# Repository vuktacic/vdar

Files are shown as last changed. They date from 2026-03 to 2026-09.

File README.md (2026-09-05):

# vdar

vdar is a low-cost 3D lidar scanner using the TF-Luna. It can generate point clouds of it's environment, which can be visualized with [vvis](./vvis). vdar is completely open source, and was designed for Hack Club's [Stasis program](https://stasis.hackclub.com). vdar was also exhibited at [Open Sauce 2026](https://www.opensauce.com/)

I created vdar because of a general interest in LiDAR. I've been playing with point clouds for a few years, and wanted to create a device that could generate my own clouds. I also wanted to learn how to create a mechanically more complex design, combined with designing and manufacturing an actual PCB.

[vdar Youtube Video](https://www.youtube.com/shorts/brxcMjVyBjw)

## Repo Structure

- [`./hardware`](./hardware) - Design files for vdar
  - [`./hardware/cad`](./hardware/cad) - Fusion 360 & Step design files for vdar
  - [`./hardware/pcb`](./hardware/pcb) - KiCad design files for vdar
    - [`./hardware/pcb/production`](./hardware/pcb/production) - PCB Production files (gerbers.zip)
- [`./JOURNAL.md`](./JOURNAL.md) - Development Journal for vdar
- [`./project`](./project) - Project management files for vdar
    - [`./project/assets`](./project/assets) - Media for project files
    - [`./project/docs`](./project/docs) - Assembly instructions for vdar
    - [`./project/finances`](./project/finances) - BOM & POs for vdar
- [`./vcore`](./vcore) - ESP32 firmware for vdar
- [`./vvis`](./vvis) - NodeJS visualizer for vdar

## Quick Start
Requirements:
 - PlatformIO Core
 - NodeJS
 - Python3

```bash
git clone https://github.com/vuktacic/vdar.git
cd vdar
just setup
mv ./vcore/include/secrets.h.example ./vcore/include/secrets.h
```
```bash
just build
just flash
just run
```

## Pictures
### Real life
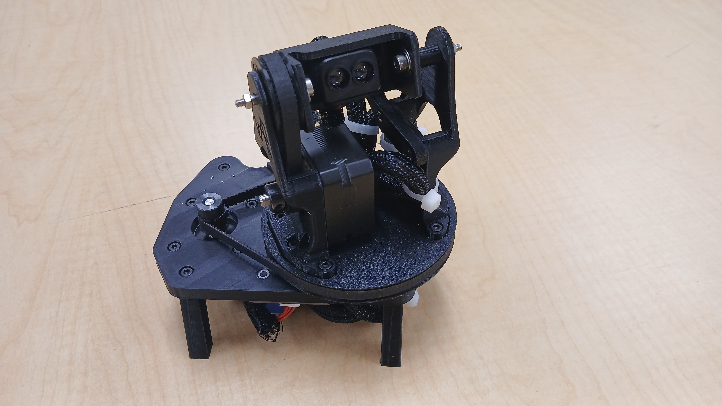
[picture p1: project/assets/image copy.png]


### Scans
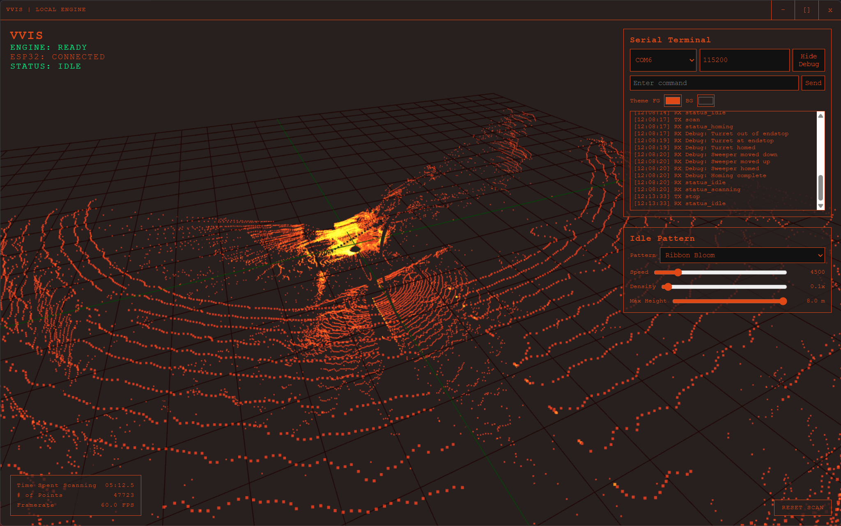
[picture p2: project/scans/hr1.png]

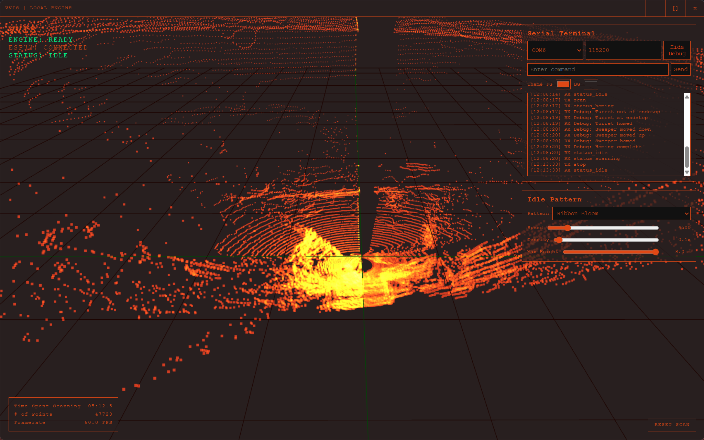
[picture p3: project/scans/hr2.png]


### 3D CAD
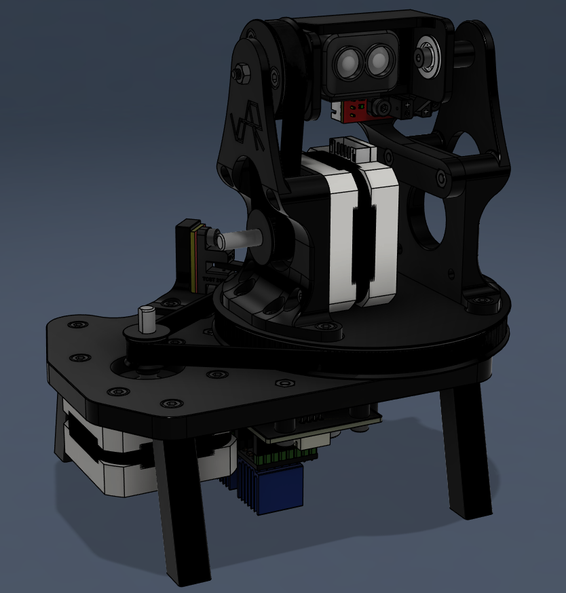
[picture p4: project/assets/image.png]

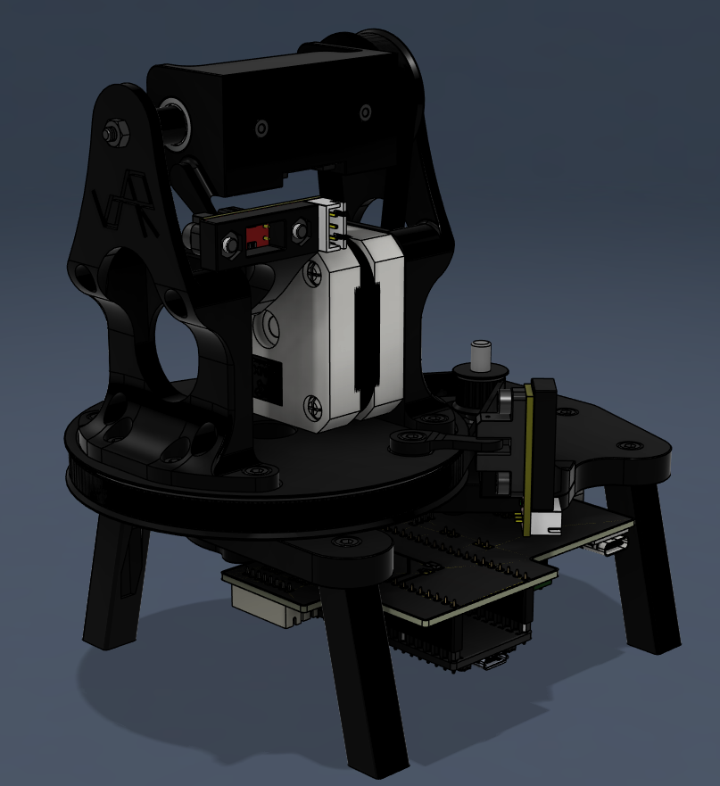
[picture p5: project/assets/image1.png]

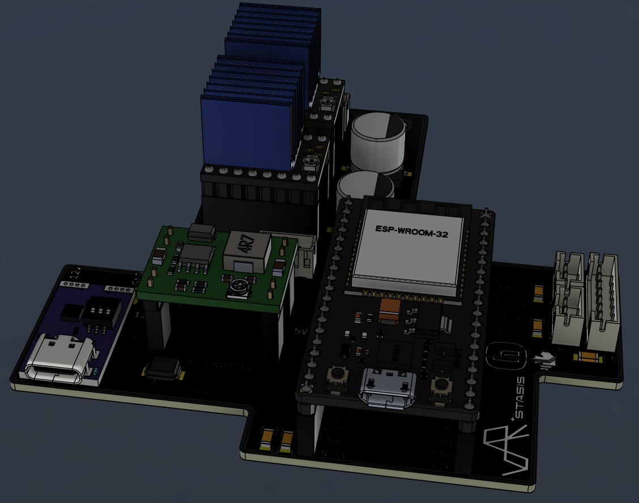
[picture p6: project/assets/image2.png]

### PCB
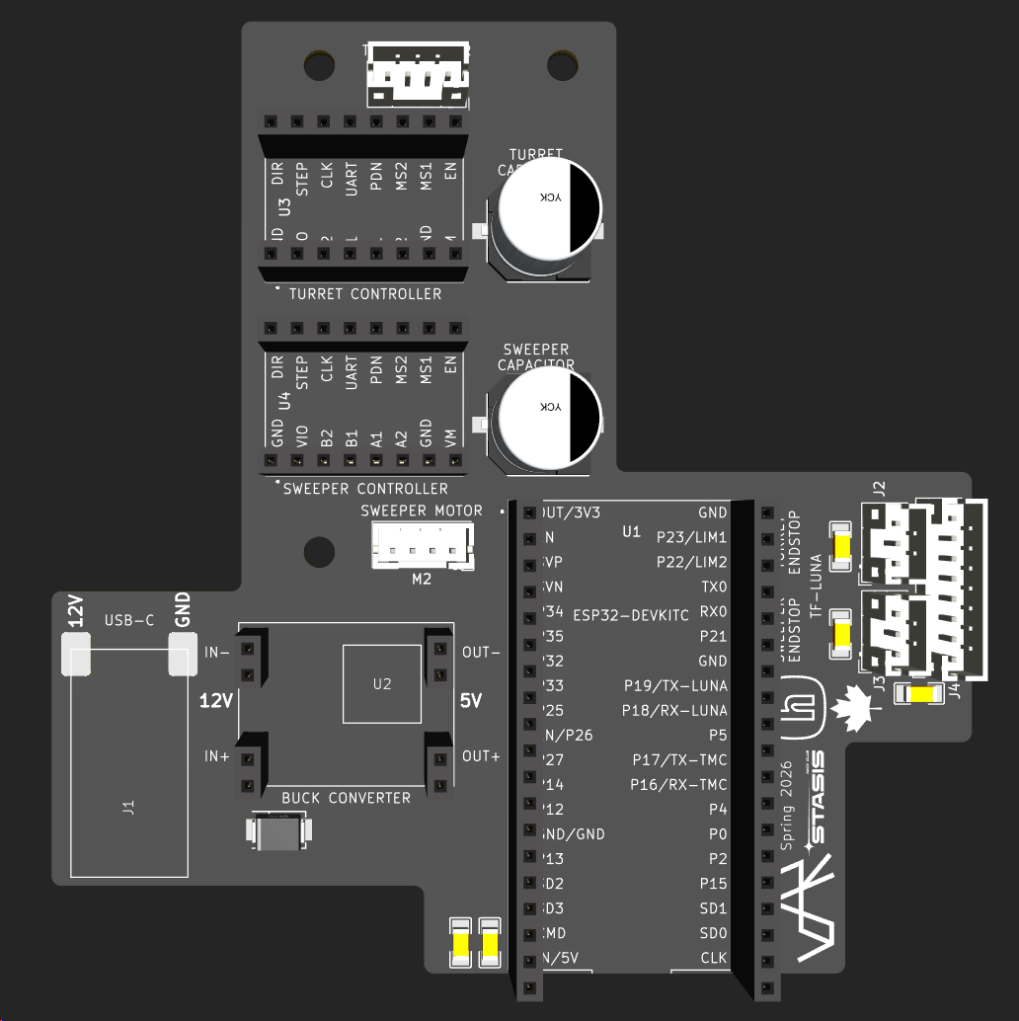
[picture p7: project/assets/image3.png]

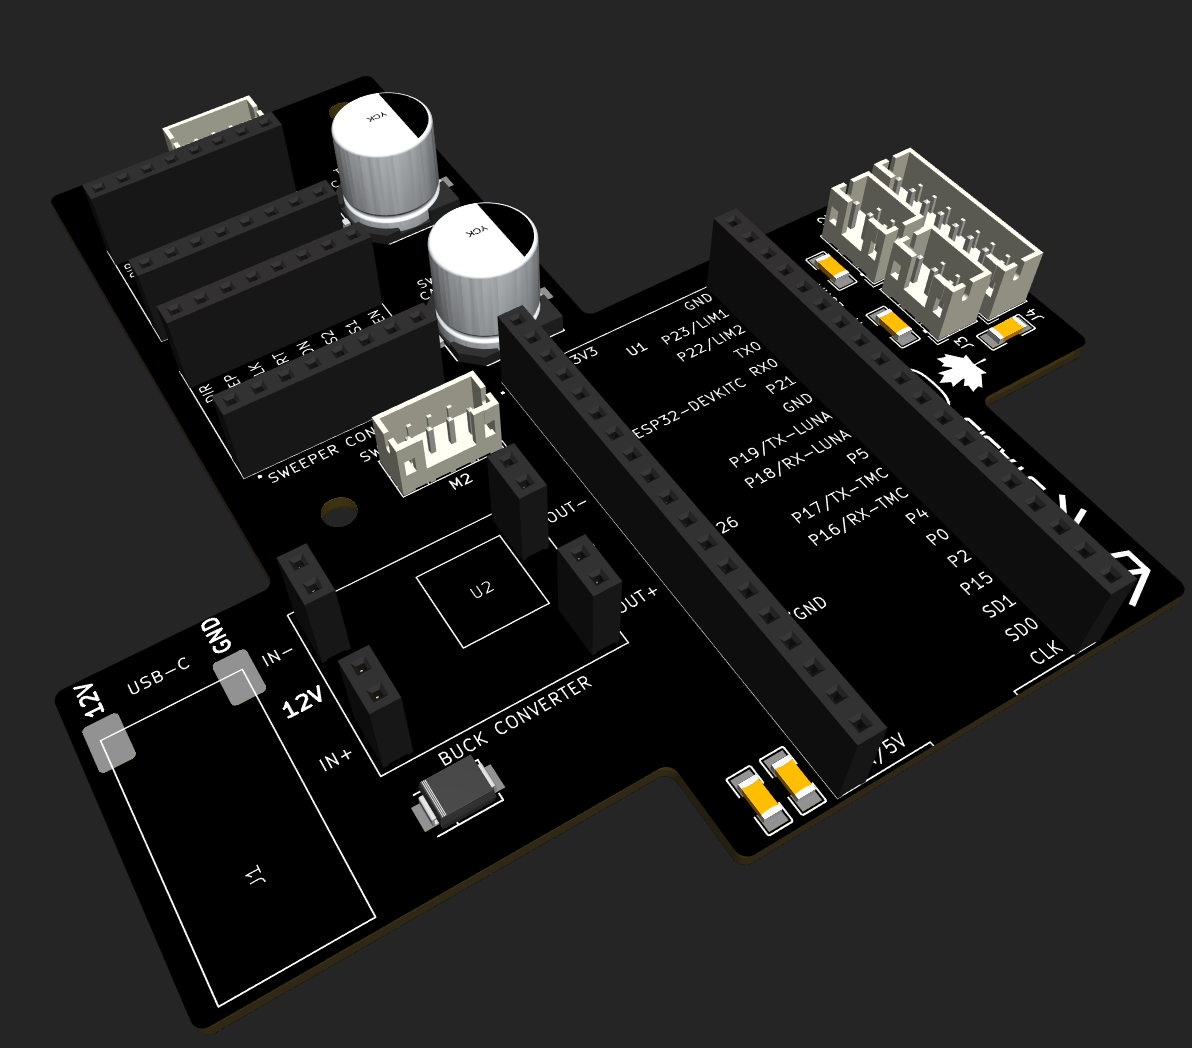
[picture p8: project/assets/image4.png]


### Offboard Wiring
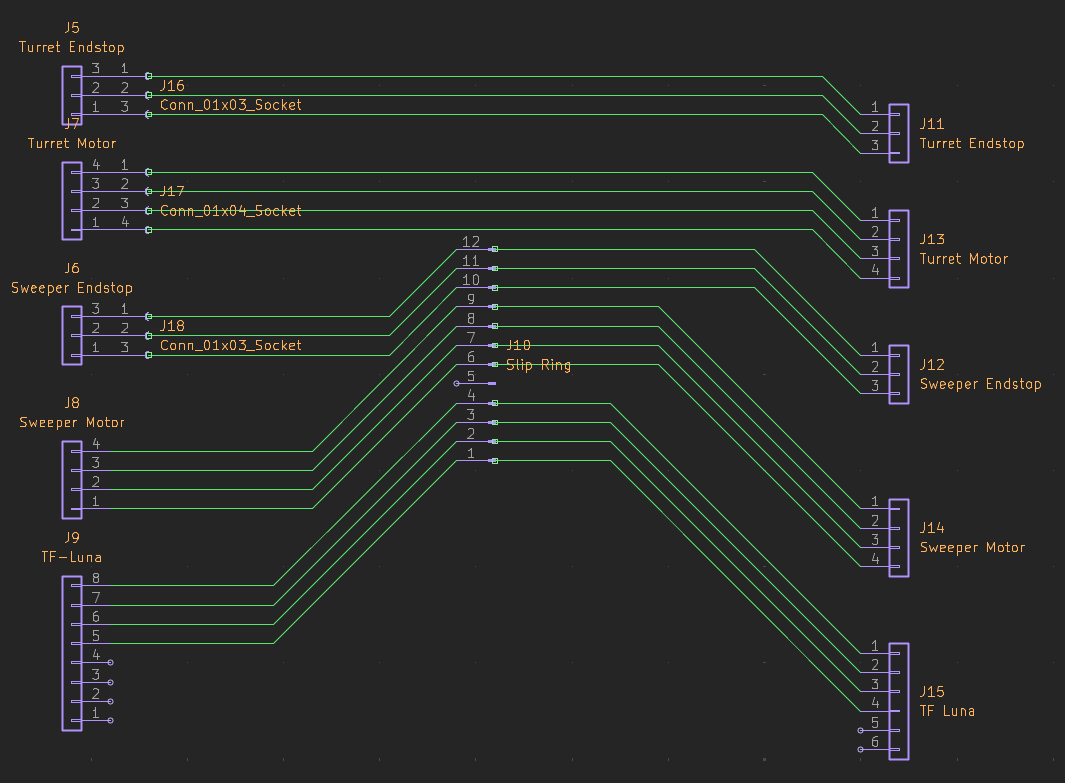
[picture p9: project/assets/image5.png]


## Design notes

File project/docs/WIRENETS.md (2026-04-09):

# Wire Nets for vdar
Map of physical labels to wire nets

## Turret Motor
- A - M1A_1
- B - M1B_1
- C - M2A_1
- D - M2B_1

## Sweeper Motor
- E - M1A_2
- F - M1B_2
- G - M2A_2
- H - M2B_2

## Turret Endstop
- I - VIN
- J - SIG
- K - GND

## Sweeper Endstop
- L - VIN
- M - SIG
- N - GND

## TF-LUNA
- O - VIN
- P - ESP-LUNA
- Q - LUNA-ESP
- R - GND

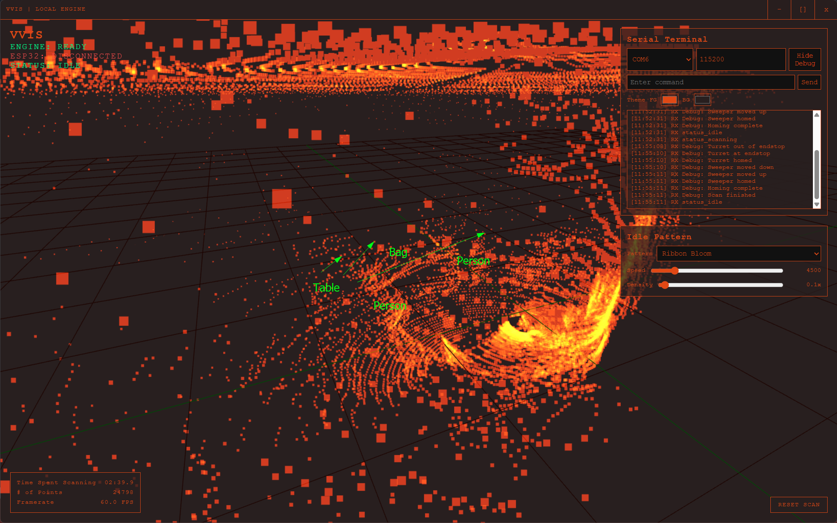
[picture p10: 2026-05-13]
project/scans/scanview2.png

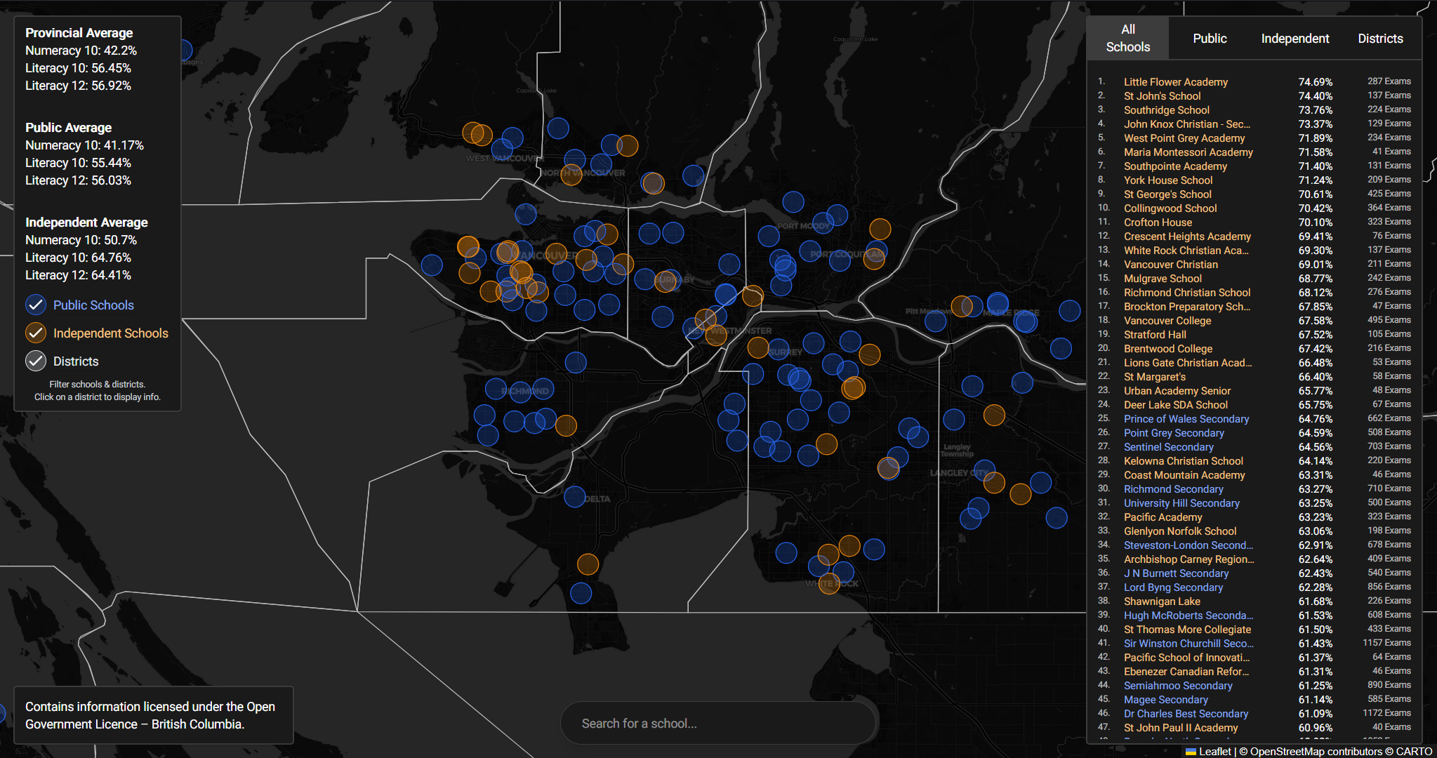
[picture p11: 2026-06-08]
project/scans/screenshot.png

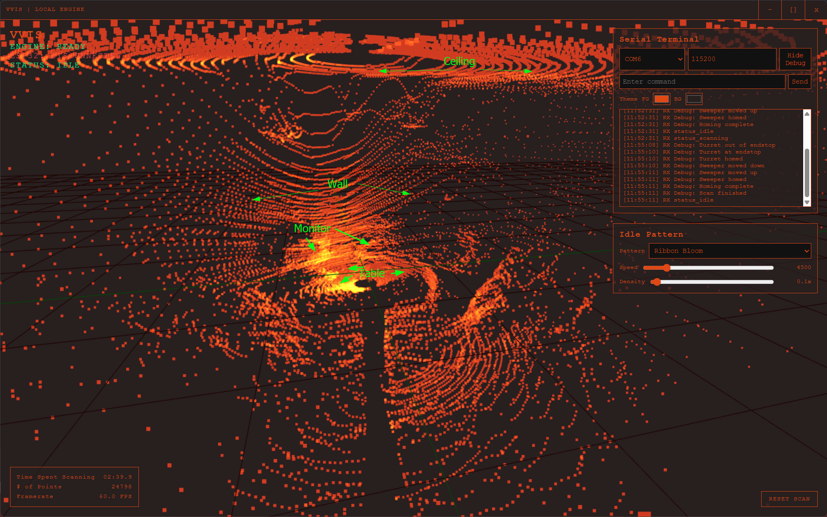
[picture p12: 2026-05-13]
project/scans/scanview1.png

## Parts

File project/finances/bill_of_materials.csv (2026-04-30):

Ordered | On-hand | Item | Vendor | Qty
:--- | :--- | :--- | :--- | :---
**Mechanical**
[x] | [x] | [NEMA 17 Motor 17HS4023](https://www.aliexpress.com/item/1005003874936862.html) | AliExpress | 2
[x] | [x] | [6804-2RS (20x32x7) Bearing](https://www.aliexpress.com/item/1005006415114490.html) | AliExpress | 1
[x] | [x] | [F604-ZZ (4x22x4) Bearing](https://www.aliexpress.com/item/1005006868220737.html) | AliExpress | 2
[x] | [x] | [165T 6mm Wide 2mm Pitch GT2 Timing Belt](https://www.aliexpress.com/item/1005005092316899.html) | AliExpress | 1
[x] | [x] | [85T 6mm Wide 2mm Pitch GT2 Timing Belt](https://www.aliexpress.com/item/1005007811742786.html) | AliExpress | 1
**3D Printed**
[x] | [x] | Main Plate | Home | 1
[x] | [x] | Bottom Plate | Home | 1
[x] | [x] | Tower | Home | 2
[x] | [x] | Yoke | Home | 1
[x] | [x] | Turret Endstop Connector | Home | 1
[x] | [x] | Sweeper Endstop Connector | Home | 1
[x] | [x] | Turret Jut | Home | 1
[x] | [x] | Leg | Home | 4
[ ] | [ ] | Yoke Right Spacer (11.8mm Long) | Home | 1
[ ] | [ ] | Yoke Left Spacer (0.6mm Long) | Home | 1
[ ] | [ ] | PCB Spacer (7.4mm Long) | Home | 3
[x] | [ ] | 144T Turret Pulley | Home | 1
[x] | [ ] | 20T Turret Pinion | Home | 1
[x] | [ ] | 45T Sweeper Pulley | Home | 1
[x] | [ ] | 25T Sweeper Pinion | Home | 1
**Fasteners**
[x] | [x] | M2x5 Hex Socket Cap Screw | Fastenal | 2
[x] | [x] | M2 Hex Nut | Fastenal | 2
[x] | [x] | M3x6 Hex Socket Cap Screw | Fastenal | 5
[x] | [x] | M3x8 Hex Socket Cap Screw | Fastenal | 10
[x] | [x] | M3x10 Hex Socket Cap Screw | Fastenal | 23
[x] | [x] | M3x16 Hex Socket Cap Screw | Fastenal | 3
[x] | [x] | M3 Hex Nut | Fastenal | 35
[x] | [x] | M3D4x20 Hex Socket Cap Shoulder Bolt | Aliexpress | 2
**Electronics**
[x] | [x] | [Benewake TF-Luna 250Hz LIDAR Sensor](https://www.aliexpress.com/item/1005009516099639.html) | AliExpress | 1
[x] | [x] | [Optical Endstop](https://www.aliexpress.com/item/1005005231591120.html) | AliExpress | 2
[x] | [x] | [TMC2209 Stepper Driver](https://www.aliexpress.com/item/1005006323811276.html) | AliExpress | 2
[x] | [x] | [MP1584EN Devboard Buck Converter](https://www.aliexpress.com/item/1005007136976280.html) | AliExpress | 1
[x] | [x] | [12 Wire 2A Slip Ring](https://www.aliexpress.com/item/1005007805413865.html) | AliExpress | 1
[x] | [x] | [USB C Decoy Board](https://www.aliexpress.com/item/1005005622939899.html) | AliExpress | 1
[x] | [x] | ESP32 DevKit-C | Home | 1
[x] | [x] | PCB | JLCPCB | 1
[x] | [x] | [35V 470μF Capacitor](https://www.aliexpress.com/item/1005006853348605.html) | Aliexpress | 2
[x] | [x] | [25V 10μF 1206 Capacitor](https://leeselectronic.com/en/product/81793-smd-capacitor-10uf-25v-1206.html) | Lee's Electronics | 1
[x] | [x] | [50V 100nF 1206 Capacitor](https://www.aliexpress.com/item/1005010653487250.html) | Aliexpress | 4
[x] | [x] | [1kΩ 1206 Resistor](https://leeselectronic.com/en/product/914154-resistors-smd-1k-5-1206-20pcs.html) | Lee's Electronics | 1
[x] | [x] | [15Vrwm 16.7Vbr 24.4VC SMBJ15A TVS Diode](https://www.aliexpress.com/item/1005007161640002.html) | Aliexpress | 1
[x] | [x] | 1x3 Pin JST-PH Male Header | School | 4
[x] | [x] | 1x4 Pin JST-PH Male Header | School | 4
[x] | [x] | 1x8 Pin JST-PH Male Header | School | 3
[x] | [x] | 1x3 Pin JST-PH Female Header | School | 4
[x] | [x] | 1x4 Pin JST-PH Female Header | School | 4
[x] | [x] | 1x8 Pin JST-PH Female Header | School | 3
[x] | [x] | 1x2 Pin 2.54mm Header | School | 4
[x] | [x] | 1x8 Pin 2.54mm Header | School | 4
[x] | [x] | 1x19 Pin 2.54mm Header | School | 2
[x] | [x] | 1x3 Pin JST-PH Female to 1x3 Pin JST-XH Female Cable | School | 2
[x] | [x] | 1x3 Pin JST-PH Female to 1x3 Pin JST-PH Female Cable | School | 1
[x] | [x] | 1x4 Pin JST-PH Female to 1x4 Pin JST-XH Female Cable | School | 2
[x] | [x] | 1x4 Pin JST-PH Female to 1x4 Pin JST-PH Female Cable | School | 1
[x] | [x] | 1x8 Pin JST-PH Female to 1x6 Pin JST-XH Female Cable | School | 1
[x] | [x] | 1x8 Pin JST-PH Female to 1x8 Pin JST-PH Female Cable | School | 1
[x] | [x] | 2m of 24-32 AWG Wire | School | 1
--- | --- | --- | --- | ---

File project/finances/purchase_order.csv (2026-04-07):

Ordered | On-hand | Item | Vendor | Qty | Total Cost (CAD)
:--- | :--- | :--- | :--- | :---
**Mechanical**
[x] | [ ] | [NEMA 17 Motor 17HS4023](https://www.aliexpress.com/item/1005003874936862.html) | AliExpress | 3 | $30.66
[x] | [ ] | [6804-2RS (20x32x7) Bearing](https://www.aliexpress.com/item/1005006415114490.html) | AliExpress | 2 | $6.82
[x] | [ ] | [F604-ZZ (4x22x4) Bearing](https://www.aliexpress.com/item/1005006868220737.html) | AliExpress | 5 | $7.49
[x] | [ ] | [165T 6mm Wide 2mm Pitch GT2 Timing Belt](https://www.aliexpress.com/item/1005005092316899.html) | AliExpress | 1 | $4.61
[x] | [ ] | [85T 6mm Wide 2mm Pitch GT2 Timing Belt](https://www.aliexpress.com/item/1005007811742786.html) | AliExpress | 1 | $2.84
**Fasteners**
[x] | [x] | [M3D4x20 Hex Socket Cap Shoulder Bolt](https://www.aliexpress.com/item/1005008314676042.html) | Aliexpress | 10 | $4.59
**Electronics**
[x] | [x] | [Benewake TF-Luna 250Hz LIDAR Sensor](https://www.aliexpress.com/item/1005009516099639.html) | AliExpress | 1 | $31.18
[x] | [x] | [Optical Endstop](https://www.aliexpress.com/item/1005005231591120.html) | AliExpress | 6 | $6.89
[x] | [ ] | [TMC2209 Stepper Driver](https://www.aliexpress.com/item/1005006323811276.html) | AliExpress | 3 | $12.78
[x] | [ ] | [MP1584EN Devboard Buck Converter](https://www.aliexpress.com/item/1005007136976280.html) | AliExpress | 1 | $1.72
[x] | [ ] | [12 Wire 2A Slip Ring](https://www.aliexpress.com/item/1005007805413865.html) | AliExpress | 1 | $16.32
[x] | [ ] | [USB C Decoy Board](https://www.aliexpress.com/item/1005005622939899.html) | AliExpress | 1 | $1.98
[x] | [ ] | PCB | JLCPCB | 5 | $2.00
[x] | [ ] | PCB Shipping | JLCPCB | 1 | $1.50
[x] | [ ] | [35V 470μF Capacitor](https://www.aliexpress.com/item/1005006853348605.html) | Aliexpress | 10 | $5.23
[x] | [x] | [25V 10μF 1206 Capacitor](https://leeselectronic.com/en/product/81793-smd-capacitor-10uf-25v-1206.html) | Lee's Electronics | 5 | $1.25
[x] | [ ] | [50V 100nF 1206 Capacitor](https://www.aliexpress.com/item/1005010653487250.html) | Aliexpress | 100 | $4.31
[x] | [x] | [1kΩ 1206 Resistor](https://leeselectronic.com/en/product/914154-resistors-smd-1k-5-1206-20pcs.html) | Lee's Electronics | 20 | $2.00
[x] | [ ] | [15Vrwm 16.7Vbr 24.4VC SMBJ15A TVS Diode](https://www.aliexpress.com/item/1005007161640002.html) | Aliexpress | 20 | $4.40
--- | --- | --- | --- | --- | ---
**TOTAL OUTLAY** |  |  |  |  | **$143.06**
**TOTAL OUTLAY (USD)** |  |  |  |  | **$103.98**

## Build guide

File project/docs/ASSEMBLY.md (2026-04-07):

# Hardware Assembly

## 3D Printing

### Materials
- Black PLA

### Print Settings
- Printer: SV06
- Layer height: 0.2mm
- Infill: 15% Gyroid
- Nozzle temp: 205°C
- Bed temp: 60°C
- Print speed: 90 mm/s
- Tree supports

## Assembly Steps

1. Placeholder

## References
See BOM.md for materials list.

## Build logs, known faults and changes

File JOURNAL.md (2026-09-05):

<!--
  This journal is auto generated by Stasis.
-->

# 5/15/2026 10 PM - Finished Project!

_Time spent: 4h_

vdar is finally finished, and it can actually do scans!

There were a couple integration problems, but nothing that wasn't easily fixed. Mainly regarding exact rotation speeds & unit conversions between rps & μsteps per second. All was resolved though, and there were no catastrophic problems!





When I did my first scan, it was horrible. This was fixed by actually. I then encountered insane drift on my azimuth.



It was shifting by like 15° every rotation! At first I checked my numerical integration. That was way off. Even after fixing the integration it was cooked. I checked, and for some reason the motor was slightly inaccurate. The fix for this was to actually rezero it on every revolution as it passed through the endstop. Sounds like a bandaid fix but honestly, it works.

scanview2

scanview1

These were my first successful scans of our electronics shop! Hell yeah.

I then did another, higher density one:
hr2

hr1

and finally, I did one of my own bedroom!
next.

I also did a few more along these.

Honestly these are super hard to read unless you know what you're looking for. In my bedroom scan I was actually able to see the contours of my shelves & my monitor.

That's all for this project!










# 5/7/2026 5 PM - Wiring Cleanup

_Time spent: 3h_

I cleaned up all the wiring for vdar!

First I wrote down all the connections so that I could save them for later. I then just chopped everything short.





I then started resoldering the wires with their shorter lengths, and covering them with wire tubes.



Throughout this process there were some issues. Mainly, the slipring wires were tiny (~32 gauge) and sucked to strip, especially now that they were cut short, leading me to fight with the electronics to find space for my wire stripper.

The other issue was heat. I had to be careful to make sure that I didn't accidentally drip solder on my electronics or touch the iron to the 3d prints. When I used the heatgun to solidify the connections with heatshrink I had to use a makeshift shield to prevent it from getting it to the 3d prints.

However, it all ended up okay. I cased all the wires and ziptied them to the side, and now they're packaged really really nicely!







Proud of my work here. Next is integration hell with the code.








# 5/1/2026 5 PM - vdar build!

_Time spent: 5h_

Note that my timelapse for this session dropped a few hours b/c of camera switching errors.

---

I finally got around to building vdar!

I collected all of my parts and got everything together.

I then learned a very important lesson:
A 5.5mm hex nut does not fit in a 5.5mm hole. You. Need. Tolerances.

On an unrelated note, I learned how to turn hex nuts into makeshift heat-press inserts:





I just took my pinecil and heated up the nuts to 210°C, then guided them into the holes.

In terms of other issues, I found that the mounts for my nema on the turret were loose. The bolts were too long and there was a gap between the motor and the tower. That was fixed by quickly printing four 1mm shims and putting them into the holes.

Overall, these actions saved me about 15 hours of reprinting.

Assembling the rest was fairly trivial.



There were a couple hiccups that reminded me the importance of DFM (designing for manufacturing). Mainly clearances for inserting and tightening bolts, but I was able to pry the plastic and work around it. (This would NOT fly if it was made of aluminum.)

The belts were successfully rotating the turret & sweeper. I was worried that the tiny tooth profile I chose (GT2 2mm pitch) would cause it to just slip on the 3d printed pulleys, however that did not seem to be a problem.

I posted a video of me moving it by hand in my personal channel: https://hackclub.slack.com/archives/C08TXRBQD44/p1777646711556279

I then threaded my slipring through the center of the turret. One of the connectors was just barely too big (by like 0.5mm), so I had to disconnect a wire and finness it through & reconnect. The others fit just fine as I thread it through.



These wires are so insanely big though. I'll have to shorten them to just a few inches each, otherwise it'll be a mess for cable management.






# 5/1/2026 5 PM - LiDAR Testing

_Time spent: 1.333333333333333h_

I spent some time testing the Nemas and Lidar. I got the turret nema spinning at 5 rps (the required speed for the turret), and the sweeper nema following the path needed for the lidar scanning!

Furthermore, shaun put me onto these goated covers.
 


(I mean, not exactly put on b/c we've been using these for FRC, but he reminded me about them.)

They allow the wires to be covered up and the black colour lets them blend in super nicely with the 3d prints and components.



# 4/27/2026 4 AM - Nema Struggles

_Time spent: 5h_

Took me way too long but after five hours, I got a nema motor spinning.

(video: https://hackclub.enterprise.slack.com/files/U06SYK3M62J/F0B0CQWF2V7/20260426_194513.mp4)

It was a shit ton of trial and error. I genuinely thought my TMC2209s were faulty and I was so so close to purchasing new ones off aliexpress.




###### aftermath of session

---

There was very little documentation about my specific TMCs, so I was grasping for straws here. For most of the time, the most I could do was lock and unlock the nemas using the EN pin to hardware disable/enable them.

For some reason I just could not kick the TMCs into UART mode. I tried using single line uart. software uart. 0ohm resistor single line uart. half duplex uart. nothing. I swapped my hardwareserial pins. nothing. I started dissecting a TMC and bridged some solder gaps.



The first one did absolutely nothing. The second one started emiting magic smoke from this part of my esp32.



After I got a magic smoke refill canister I continued troubleshooting. I tried actually removing the top resistor on the tmc and that did nothing.

I tried shorting the vio pins. pulling uart up at boot. pulling it down at boot. removing the uart resistor. removing uart rx. shorting uart rx. I was actually going insane.

It was at about this time that I started thinking my boards were permanently broken and started searching on aliexpress for replacements. (I was considering leaving a nasty review on the page I purchased from).

I messed with the solder bridges on the back of my esp32, and through some miraculous reason the motor started vibrating! I kicked up the velocity and it was officially spinning at a consistent speed :)

It was a lot of work today, but now that that is all done, I can focus less on *making a motor move* and more on *making it move in interesting ways.*






# 4/17/2026 7 PM - Solder Update

_Time spent: 5.833333333333333h_

# Soldering
This journal entry is a collection of five sessions done during my spare period at school.

My PCB arrived and I was able to start soldering. This was the first time I did SMD components. The first one was shitty, but everything after that went beautifully.







After that I started soldering my JST-PH connectors. THT is nice to solder.



More parts arrived and I finally had all of my electrical components.



Also got some super nice black NEMAs





Following that I soldered the rest of my 2.54 female headers. I tested each part of the board and turned it on for the first time!





All the voltages were good and there were no issues! (Shocking.)

Right now its a lot of wire soldering. I had to create the JST-PH jumpers to go to the endstops and luna. (Its kinda hard to see in the photo but its circled).



Only other things I need to solder are the Luna wires on the fixed part of vdar and the NEMA wires! I also need to start my 3d prints too.












# 4/9/2026 6 PM - Some Parts Arrived + Wire Nets

_Time spent: 1h_

Some of my parts arrived!

I got my TF-Luna LiDAR sensor, my 12 wire slip ring, half of my bearings, and all of my fasteners!





The first thing im noticing is how small these things are. When you're cading its hard to pay attention to the scale of stuff, but now that my components are arriving it's hitting me just how compact vdar will be.

I took my lidar sensor to school and tested all the pins with a multimeter to make sure that it matched the datasheet. (Some people on aliexpress mentioned that they mixed up their 5V and GND wires and fried the $30 sensor).

I then spent some time assigning wirenets. My school's electronics shop has these neat labels that make it super easy to track wirenets. With cuber, there were tons of wires and I wasted so much time following them back to the source to discover what they were for. With the labels, I can hopefully prevent that wild goose chase and immediately be able to reference the purpose of each wire.













# 3/25/2026 12 AM - 3d Model, BOM, & PO

_Time spent: 5.066666666666666h_

Hey y'all. Today I can say with 100% certainty that my CAD, BOM, and PO are complete.

I added the missing socket headers to my pcb:



I then imported the model into fusion 360:



Because of a mishap, my bottom legs actually intersected with the PCB. To avoid rearranging and rerouting it, I just moved them 1cm down to avoid intersections.

I then went on a search for models of all my dev boards, which included a wild goose chase for a 0.9" wide ESP32 (all the models online were 1" wide). By pure luck I found one uploaded by a user 15 years ago on a Dassault Systems forum.





I hit another issue. The heatsinks on my TMC2209's were too tall and conflicted with the ground. All this needed was a simple fix of lengthening the legs.

I then 100% finalized my BOM & PO. I created a big list of every single part used & its quantity needed, as well as a purchase order for what needed to be bought.





I'm sourcing my bolts through Fastenal (except for the specialty shoulder bolts).

WIth that complete, The moment I finish my software I can submit this for review.








# 3/24/2026 12 AM - PCB Routing

_Time spent: 8.85h_

Jesus that was a long session. I'm currently writing this the afternoon after (I stayed up until 1:30am working on this).

I basically finished my PCB in this session. I first started off with swapping my 12V/GND for an actual usb port for schematic parity:

I then started fixing ERC errors. This involved putting a lot of NC (no connection) flags on my unused pins:



I also created footprints for my buck devboard (it doesn't use a standard layout for some reason?)



and my USB C PD devboard:



and added labels for my TMC motor drivers:


and my esp32 devboard:



I set the pinout silkscreens on the interior of the boards for compactness. They'll be hotswappable so I can always pull it out to check and verify.

I then assigned footprints to all my parts.
For my sensor connections I'm going with JST-PH connectors on a 2.00mm pitch. It's what it is used for REV NEO/NEO550 motors and so there are tons I can nick some from. However I will need to use a 8 pin connector for my lidar. This is because we ran out of 6 pin connectors (I wonder why 🤔).

I had to spend a lot of time deleting non existent pins from my schematic so that there was parity with my footprints.

I then marked out no go zones in the pcb editors and started laying out everything.



The bottom right mounting hole was being super annoying in terms of placing components, and so I removed it to make room for my esp32 devboard.



I spent a bit of time debating whether I should flip one of the motor controller and capacitor pairs. The reasoning for this is that it would allow for identical routing on both sides. Alas the current setup was good enough, and fit under 100mmx100mm.

I had a nice dinner, and then sat down at my desk at 9:30pm for a nearly four hour work block.

I first started with precisely aligning components (adjusting from the rough placements I made earlier).

I got some advice from my friends, where they said I should focus on routing important signal first, then important power.

I routed my sensor jst connectors first.



And then my obnoxiously large 12V rails.



I had to move a motor jst connector down to allow for routing space.

I then filled in the rest of my traces—resistors, capacitors, and solderbridges.

I also increased the thickness of my 5V rail slightly.







Here I had to play with my 12V rail and UART lines so that they wouldn't overlap or run parallel. Some research (and advice from Scott) said it wouldn't affect it too much, but better safe than sorry.

I then ran ground pours to complete the board. After some DRC's with Scott's help, I made sure all my ground planes were connected, I had a working PCB!

Spoke with some friends at 12AM (lol) about drawing some art to put on my silkscreen (TBD).

I then adjusted all my routing to "beautify" the board:



I then added important silkscreen information and some personalization!







Thats a long session. For today I'm just going to round some corners, place some 3d models, and then import it into Fusion 360 to complete the CAD.



















# 3/22/2026 8 PM - Schematic & Footprint

_Time spent: 1.683333333333333h_

Hey y'all. This is the journal entry for yesterday that I wasn't able to write due to being cut short for an event.



Modified the schematic a little bit. I changes my backflow protection to a TVS diode. The way it works is under normal operation, it blocks electricity passing through. However if the voltage were to spike, the it would clamp closed and let the voltage pass through to ground.



In terms of other things I did, I adjusted my esp32 devkit footprint from 1" wide to 0.9" wide to accomodate for the devboard I already have on hand. I also swapped some pin numbers for the TMC2209 to match the aliexpress version.










# 3/21/2026 7 AM - Slogged through a KiCAD schematic

_Time spent: 6.05h_

I'm so glad I'm not going into electrical engineering.



Finished schematic. At least I think it's finished.

I basically connected everything today. I spent way too long figuring out the correct connections for the TMC2209 modules. Apparently they do single way UART? I don't really understand, but a website told me to do this funky thing with my tx/rx pins on the esp32:



If it's not clear, I'm choosing UART over the low level step & dir control due to configurability of current, microstepping, and everything else on the sensor.

I also connected the TF-Luna to the esp32:

.

Now in terms of problems, I foudn that my buck converter schematic was bs, and so I had to go find one that had a similar pinout to the MP1584EN. Kinda sucked.

I then added some beefy 470uF capacitors to the 12VIN of the TMC2209s, which would keep the line steady through voltage ticks from the Nemas.



I did something similar for the ESP32, which would help filter out voltage spikes on 5VIN.



And again on my optical endstops and TF-Luna.




Part of this whole process included sourcing exact components from JLCPCB/LCSC, which adds to my BoM cost by a few dollars.

I'm not in a very good mood after today. It was basically 6 hours of me using Gemini as a crutch for pcb design. Let's hope tomorrow is a little better.

TODO
---
### PCB
- [x] CAD schematic
- [ ] Verify footprints
- [ ] Place components
- [ ] Route wires
- [ ] Place mounting holes
- [ ] Add personalization ✨ (again)









# 3/20/2026 4 AM - Finished 3D Cad

_Time spent: 6.25h_



Hey y'all. I finished my 3D cad for vdar. Today was really spent knocking out all the little jobs from my todo list from yesterday:

- [ ] Add the second optical endstop
- [ ] Add the shoulder bolts (axles)
- [ ] Add the turret endstop jut
- [ ] Add the sweeper endstop jut
- [ ] Add mounting legs
- [ ] Add PCB mount & case
- [ ] Parameterize all nut pockets
- [ ] Add fasteners to the CAD
- [ ] Make sure all bolt lengths are sensible & that all hex/counterbore pockets exist.
- [ ] Fillet everything
- [ ] Add personalization ✨
---
- [x] Add the turret endstop jut



First thing I did today was add the jut for the turret endstop. I had to do a little research, but I found that the sensor is considered "covered" when half of the tiny viewing hole is covered. Nothing else to really add to this.

---
- [x] Add the second optical endstop
- [x] Add the sweeper endstop jut



To reduce the number of unique parts, I repurposed the nema mounting holes on the opposite tower rather than design an entirely new one. I used the same layout as the first endstop, and so this was a particularly easy job. I also added a jut to the yoke, being careful about ensuring it was still easy to 3d print.

---
- [x] Add the shoulder bolts (axles)



For the actual axle of the yoke, I'm using M3 shoulder bolts (picture above). Keeping it M3 allows for consistent hardware, and the shoulder makes a nice smooth surface to rotate around.

This is where I hit my first roadblock. The two closest shoulder bolt sizes were 18mm and 20mm long. My yoke required a 19mm bolt. I had to move the tower face by 1mm on both sides, and then resize the spacers involved.

Somewhere along the way, I knocked the sensor off the origin. This means that when the turret rotates around, it would be moving eccentrically and all the measurements would be wonky. I had a 20 minute stint where I was toying with joints to fix this error. Fortunately it worked itself out and I did not have to redesign any components.

---
- [x] Add mounting legs



Lofted these legs down to give vdar a stable base (as opposed to resting on the nema).

Not much to say about this. It kinda looks like a dog now.

I might want to reduce the length of the hex nut pockets in the future for strength.

---
- [x] Add PCB mount & case



I'm planning on mounting the pcb beneath the main plate (yellow spacers). This will prove challenging due to how cramped it is, but will be a nice challenge in designing an unorthodox pcb shape.

Why beneath? Well it packages really nicely, and a large upright wall would actually block the lidar's view whenever it spins through it.

---
- [x] Parameterize all nut pockets
- [x] Add fasteners to the CAD
- [x] Make sure all bolt lengths are sensible & that all hex/counterbore pockets exist.






Paramterized the nut pockets, which means based on a future 3d print test I can easily adjust the sizes of all pockets 👍

Added some nice black oxide fasteners. Part of this included making sure all of the bolt lengths were flush and did not stick out (very important for the main plate and turret pulley, because there is 1mm of clearance between them) (doubly important for the bottom plate, as the bolts absolutely CANNOT stick out or they will fuck up my $7 bearing.

---
- [x] Fillet everything
### "The easiest way to make your shitty 3d models look good"











I used a standard 0.25mm fillet on edges and corners, and a vibes-based fillet on everything else.

Also: I made sure to include a 0.5mm chamfer on my bearing and motor boss holes so that they would automatically align themselves when I press them in.

---
- [ ] Add personalization ✨



Made a geometric-esque logo in Figma and put it on the sides of the tower. Idk I'm not a graphic designer.

---
And with that, the 3D CAD is complete! I moved on to getting my KiCAD schematic down.



This is what I got done in the 30 minutes before my brain turned to mush. I'm going to be honest I don't really know what I'm doing. I sent this screenshot to Gemini and it turns out I've already somehow fried my esp32. That's a job for tomorrow.

---
TODO LIST:
### PCB
- [ ] CAD schematic
- [ ] Place components
- [ ] Route wires
- [ ] Place mounting holes
- [ ] Add personalization ✨ (again)



















# 3/19/2026 6 AM - vdar: 80% done 3d CAD

_Time spent: 5.533333333333333h_

Hey y'all. I'm trying to do a better job at journalling, so I'll make this one more thorough.

---

Today I finished most of the top assembly of vdar.



Right now it's in a state where ~80% of the 3d cad is done. I'll talk about my next steps near the end of this entry.

My first issue when I sat down at my laptop today was how the fuck I was going to package everything.



I was immediately hit with a dillema: figure out how to packaghe this (comparatively) gigantic Nema 17 on my turret, or increase the size of my pulley.

I opted against option 2 because of three reasons:

1. Increasing the size would massively increase print time (my 90mm pulley is already a 4 hour print)
2. Increasing the pulley size would screw up my steps to degrees calculations (forcing me to not use whole numbers for the lidar math)
3. Keeping the same pulley size and adding a wider "brim" would lead to the same issue as reason 1.

I already had experience packaging tight things in FRC (much to the dismay of our assembly team), and figuring this out would provide a nice mental challenge for myself.

---
In true avoidant fasion, I did neither of the two options (although I was already set on #1). I actually started with the yoke first, so that I could figure out how much space I needed for my supports.



The yoke was modelled to fit the TF-Luna lidar sensor.

By the way, for some reason the tf-luna uses M2 bolts for mounting. Do you know how fucking hard it is to find M2 bolts?? Home depot doesn't have them. Rona/Lowes doesn't have them. The weird speciality stores don't have them. I'm not dropping $10 on a 50 pack just for two fucking bolts.

THANKFULLY, I have a contact who regularly orders hardware from Fastenal, and I can tack on my M2 bolts on the purchase order for a few cents each.

On the walls of the yoke are two bearing holes. After deliberation I decided to put them on the yoke directly. If they were on the towers of my turret, then the yoke plastic could bend and deflect downwards. A bearing has higher surface area, and is much less likely to deflect the 3dp walls of the yoke. If the tower mounts were to deflect, then the yoke would remain rigid.

This is a really fancy way of saying that putting them on yoke makes it easier to keep the assembly stiff👍

---

I hit my first problem here. I was originally planning on using a 20T pinion pulley with a 36T deadaxle yoke pulley (deadaxle = mounted directly to the face instead of transmitting through the axle). The problem I hit was that when I added the hex pockets for my M3 nuts, they actually conflicted with the flange of my bearing.

The solution was to update my pulley sizes. I went from 20T-36T to 25T-45T. The 45T pulley was wide enough for the deadaxle mounting bolts to not conflict with the bearing flange while still allowing for an exact 1.8:1 ratio. (Why 1.8:1? With that ratio then one step on the Nema (1.8°) is transformed into exactly 1° on the driven pulley -> this simplifies my lidar math.)

---

With the yoke cadded in, I could then continue with my actual packaging. With the given pulley ratios, I used Recalc and found that an 85T belt would give me a center to center distance that was sensible in terms of turret height (sensible = good vibes, I'm vibecading. [not ai, but cading based on vibes])



I then designed this absolute monstrosity of a 3d printed part.



I was in a trance when I made this. None of the fillets are standardized. Extrusion lengths were based on vibes. Holes were placed by throwing darts at my screen. It's beautiful.

I pocketed my turret pulley to allow for easy alignment of the towers. I then had to connect a bottom "foundation", a Nema mounting plate, and an axle holder all in one continuous part.

Spoiler alert: lofts are shit. I don't want to talk about it.

I extruded different sections of my Nema mounting plate to different distances so as to make the three objects connect. Once they were combined, I created mounting holes and then filleted the fuck out of the piece to make it presentable.





One thing to keep in mind is that I had to constantly be mindful of where I was mounting my Nema—The center hole in my turret is where all the wires pass through, and I had to keep a portion of it exposed so that I can, you know, actually route the damn wires.

Next steps
---
I've got a lot of stuff that I need to do, so I'll probably just dump it all here for myself:

### 3d CAD:
- [ ] Add the second optical endstop
- [ ] Add the shoulder bolts (axles)
- [ ] Add the turret endstop jut
- [ ] Add the sweeper endstop jut
- [ ] Add mounting legs
- [ ] Add PCB mount & case
- [ ] Make sure all bolt lengths are sensible & that all hex/counterbore pockets exist.
- [ ] Add fasteners to the CAD
- [ ] Fillet everything
- [ ] Add personalization ✨

### PCB
- [ ] CAD schematic
- [ ] Place components
- [ ] Route wires
- [ ] Place mounting holes
- [ ] Add personalization ✨ (again)

### Firmware
- [ ] Do the damn math
- [ ] Write the output (motor control) code.
- [ ] Write the input (measurement) code.
- [ ] Write the bridge (communication) code.

### Software
- [ ] Do the damn math
- [ ] Write the bridge code
- [ ] Write the calculations
- [ ] Write the visualizer code.
- [ ] Write the control code

### General
- [ ] Finalize BOM
- [ ] Finalize Purchase Order

Fuck thats a lot.

# When you dig yourself into a hole the only way out is up 🤷‍♂️










# 3/18/2026 12 AM - CAD Design

_Time spent: 5.083333333333333h_

Got started with the CAD for vdar. I got most of the main base in, with the Nema 17 and timing belt system used to rotate the assembly. I also added in a connector for my optical endstop.


Current CAD progress

I spent a fair bit of time on the bottom plate.




Bottom Plate Pictures

This will be one of the most complex portions of the CAD due to how many lengths need to be precise. It keeps the main bearing from falling through while also holding the slip ring for my wires. I needed to ensure that it had the correct thicknesses so as to prevent any bolts or nuts from sticking up and interfering with the bearing or carriage.

My brain is pretty close to mush rn so I'll probably continue this tomorrow—don't expect any more work to be done today.





# 3/17/2026 7 AM - Bill of Materials

_Time spent: 2.916666666666667h_

Spent tonight working on a BoM for my project.

The basic premise for vdar is a functional 360° lidar scanner. This would require a a sensor being swept 180° on top of a 360° rotating platform. I've chose the TF-luna as my sensor due to having good range (0.2m-8m) and a high(er) framerate (250hz), which allows 3d scans to complete in a sensible timeframe (4 mins vs 10+ mins).

I spent *many* showers coming up with the archetype for vdar, meaning that I'm coming into this with a solid idea of what I want to build and (more importantly) how I will do it.

The total cost for the BoM comes out to $140cad ($102usd), however that will raise by a few dollars as I figure out the GT2 belt lengths I want to use for my motion.


Aliexpress total


Crappy sketch of the project I drew




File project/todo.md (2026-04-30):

CAD Tolerances:
- [x] Bearings: +0.2mm
- [x] Motor Boss: +0.4mm
- [x] Smooth Fit: +0.4mm (0.2mm each side)
- [x] Shaft Hole: 4.3mm
- [ ] Pulley Fit: 5.4mm dia 2.15mm ridge
- [ ] Turret Plug-in Fit: 20.10mm

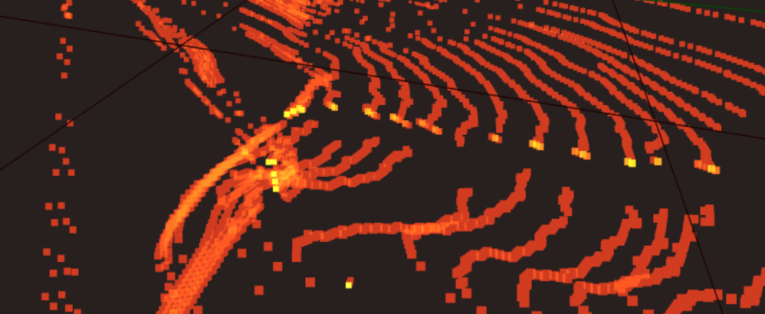
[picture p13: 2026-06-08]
project/scans/density issue.png

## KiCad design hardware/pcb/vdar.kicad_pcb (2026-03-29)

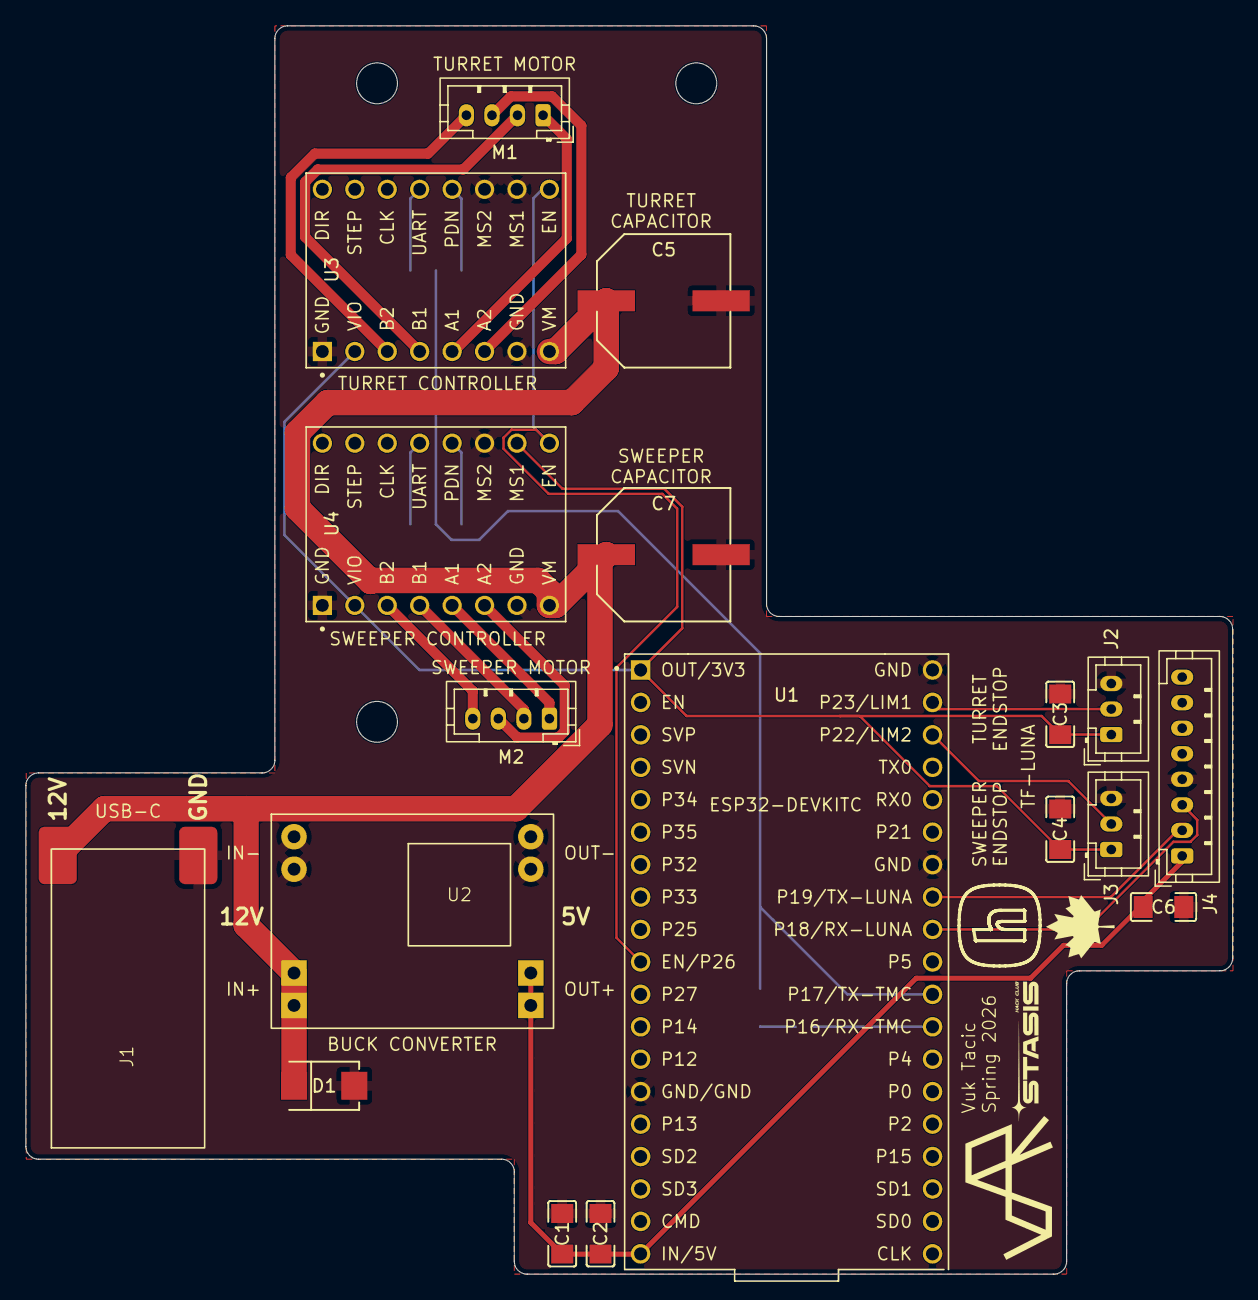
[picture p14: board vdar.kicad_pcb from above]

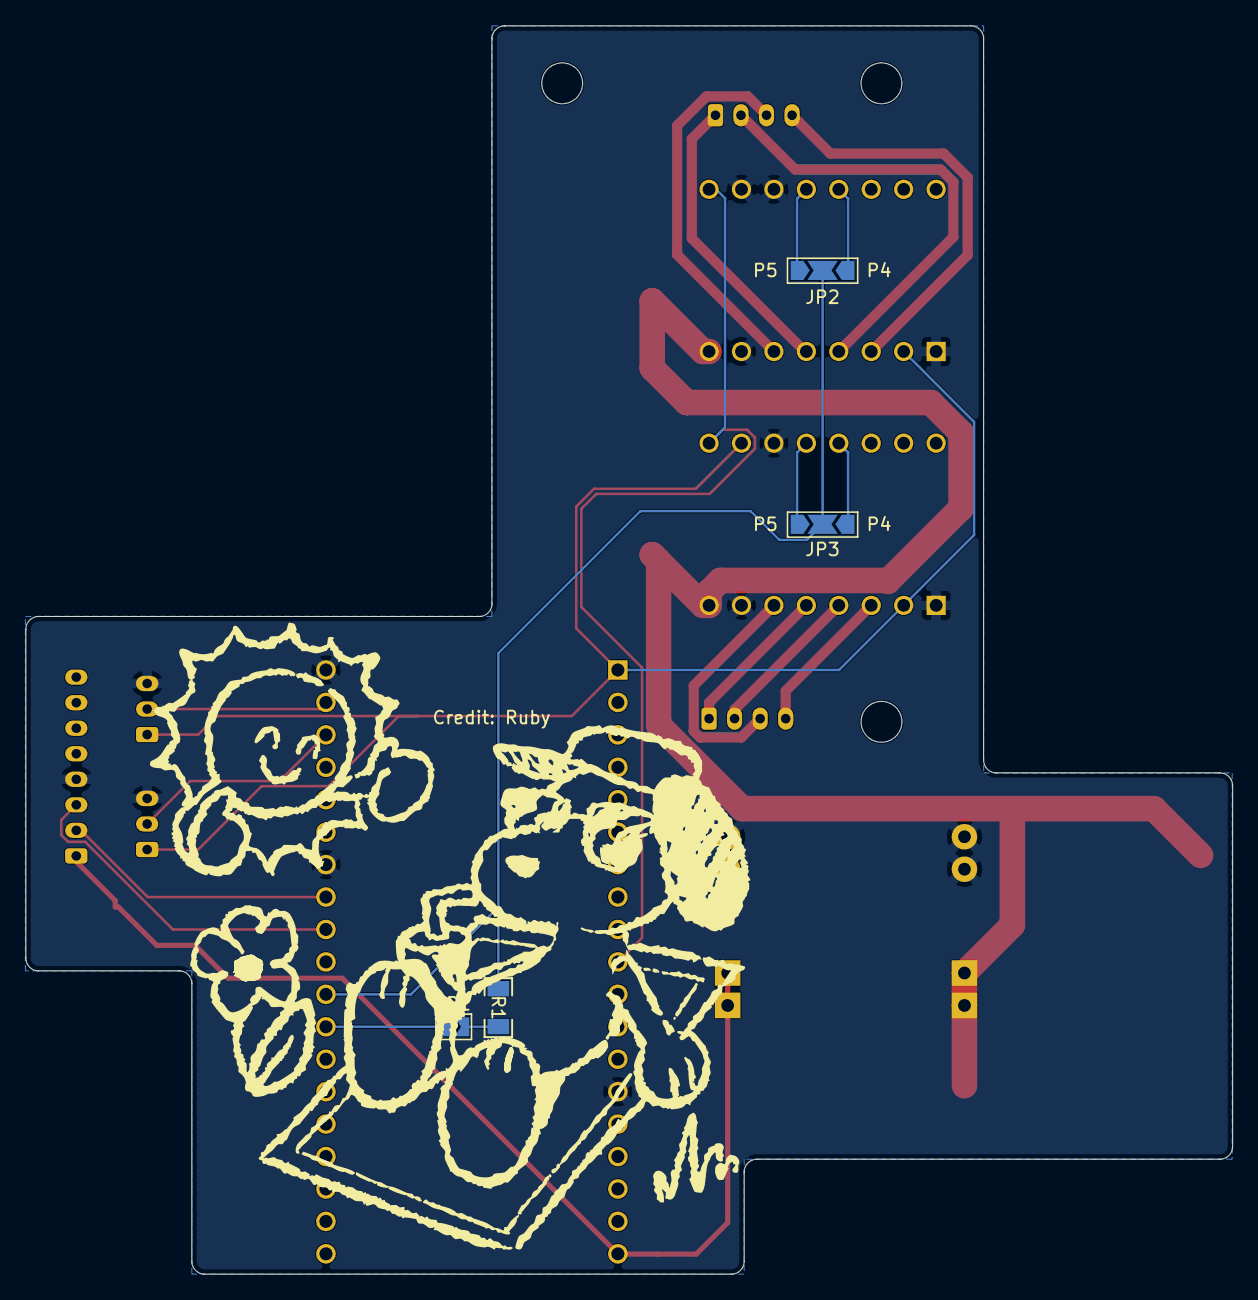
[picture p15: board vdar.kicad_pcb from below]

Board: 2 copper layers, 94.5 x 97.8 mm, 26 parts (4 on the bottom side), 24 nets.

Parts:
C1: 16V 10uF; C1206
C2, C3, C4, C6: 100V 100nF; C1206
C5, C7: 35V 470muF; CAP-SMD_BD10.0-L10.3-W10.3-LS11.0-FD
D1: 15Vrwm 16.7Vbr 24.4VC; SMB_L4.6-W3.6-LS5.3-RD
H1, H2, H3, H4: MountingHole; MountingHole_3.2mm_M3_Clearance
J1: USB C PD Board 12V 5A; USB_C_PD_BOARD
J2, J3: Optical Endstop; JST_PH_B3B-PH-K_1x03_P2.00mm_Vertical
J4: TF-LUNA; JST_PH_B8B-PH-K_1x08_P2.00mm_Vertical
JP1: SolderJumper_2_Open; SolderJumper-2_P1.3mm_Open_TrianglePad1.0x1.5mm
JP2, JP3: SolderJumper_3_Open; SolderJumper-3_P2.0mm_Open_TrianglePad1.0x1.5mm_NumberLabels
M1, M2: Nema 17; JST_PH_B4B-PH-K_1x04_P2.00mm_Vertical
R1: 1000Ω; R1206
U1: ESP32-DEVKITC; MODULE_ESP32-DEVKITC_VDAR
U2: MP1584EN Buck Converter; MP1584EN
U3, U4: TMC2209_SILENTSTEPSTICK; MODULE_TMC2209_SILENTSTEPSTICK_INTERNAL SILKSCREEN

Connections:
3.3V: C3.1, C4.1, J2.1, J3.1, U1.1 (3V3), U3.2 (VIO), U4.2 (VIO), U4.15 (MS1)
5V: C1.1, C2.1, C6.1, J4.1, U1.19 (EXT_5V), U2.1 (+VDC)
12V: C5.1, C7.1, D1.1, J1.A9 (VBUS), U2.5 (VIN+), U3.8 (VM), U4.8 (VM)
EN: U1.10 (IO26), U3.16 (~EN), U4.16 (~EN)
ESP-LUNA: J4.2, U1.31 (IO19)
ESP-TMC: JP2.2 (C), JP3.2 (C), R1.2, U1.28 (IO17)
GND: C1.2, C2.2, C3.2, C4.2, C5.2, C6.2, C7.2, D1.2, J1.A12 (GND), J2.3, J3.3, J4.4, U1.14 (GND1), U1.32 (GND2), U1.38 (GND3), U2.3 (-VDC), U2.7 (VIN-), U3.1 (GND), U3.7 (GND), U3.14 (MS2), U3.15 (MS1), U4.1 (GND), U4.7 (GND), U4.14 (MS2)
LIM1: J2.2, U1.37 (IO23)
LIM2: J3.2, U1.36 (IO22)
LUNA-ESP: J4.3, U1.30 (IO18)
M1A_1: M1.1 (-_1), U3.5 (M1A)
M1A_2: M2.1 (-_1), U4.5 (M1A)
M1B_1: M1.2, U3.4 (M1B)
M1B_2: M2.2, U4.4 (M1B)
M2A_1: M1.3, U3.6 (M2A)
M2A_2: M2.3, U4.6 (M2A)
M2B_1: M1.4, U3.3 (M2B)
M2B_2: M2.4, U4.3 (M2B)
unnamed: JP1.1 (A), U1.27 (IO16)
unnamed: JP1.2 (B), R1.1
unnamed: JP2.1 (A), U3.12 (UART)
unnamed: JP2.3 (B), U3.13 (PDN)
unnamed: JP3.1 (A), U4.12 (UART)
unnamed: JP3.3 (B), U4.13 (PDN)

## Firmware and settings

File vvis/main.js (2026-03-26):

const { app, BrowserWindow, ipcMain, screen } = require('electron')
const path = require('node:path')
const { SerialPort } = require('serialport')

let mainWindow = null
let activePort = null
let pseudoMaximized = false
let lastNormalBounds = null
const RESTORE_PRESET_WIDTH = 1280
const RESTORE_PRESET_HEIGHT = 820

function sendToRenderer(channel, payload) {
    if(mainWindow && !mainWindow.isDestroyed()) {
        mainWindow.webContents.send(channel, payload)
    }
}

function getWindowStatePayload() {
    if(!mainWindow || mainWindow.isDestroyed()) {
        return { maximized: false }
    }

    return { maximized: Boolean(mainWindow.isMaximized() || pseudoMaximized) }
}

function clamp(value, min, max) {
    if(value < min) {
        return min
    }
    if(value > max) {
        return max
    }
    return value
}

function getDisplayForWindow(preferredPoint) {
    if(preferredPoint && Number.isFinite(preferredPoint.x) && Number.isFinite(preferredPoint.y)) {
        return screen.getDisplayNearestPoint(preferredPoint)
    }

    const bounds = mainWindow.getBounds()
    const center = {
        x: Math.round(bounds.x + (bounds.width / 2)),
        y: Math.round(bounds.y + (bounds.height / 2))
    }

    return screen.getDisplayNearestPoint(center)
}

function getDefaultNormalBounds(display) {
    const workArea = display.workArea
    const width = clamp(RESTORE_PRESET_WIDTH, 640, workArea.width)
    const height = clamp(RESTORE_PRESET_HEIGHT, 480, workArea.height)
    const x = Math.round(workArea.x + ((workArea.width - width) / 2))
    const y = Math.round(workArea.y + ((workArea.height - height) / 2))
    return { x, y, width, height }
}

function normalizeBoundsToDisplay(bounds, display) {
    const workArea = display.workArea
    const width = clamp(bounds.width, 640, workArea.width)
    const height = clamp(bounds.height, 480, workArea.height)
    const x = clamp(bounds.x, workArea.x, workArea.x + workArea.width - width)
    const y = clamp(bounds.y, workArea.y, workArea.y + workArea.height - height)
    return { x, y, width, height }
}

function getLastNormalBounds(display) {
    if(lastNormalBounds) {
        return normalizeBoundsToDisplay(lastNormalBounds, display)
    }

    return getDefaultNormalBounds(display)
}

function trackLastNormalBounds() {
    if(!mainWindow || mainWindow.isDestroyed()) {
        return
    }

    if(pseudoMaximized || mainWindow.isMaximized()) {
        return
    }

    lastNormalBounds = mainWindow.getBounds()
}

function applyPseudoMaximize(preferredPoint) {
    if(!mainWindow || mainWindow.isDestroyed()) {
        return
    }

    if(mainWindow.isMaximized()) {
        mainWindow.unmaximize()
    }

    if(!pseudoMaximized) {
        trackLastNormalBounds()
    }

    const targetDisplay = getDisplayForWindow(preferredPoint)
    const displayBounds = targetDisplay.bounds
    mainWindow.setBounds(displayBounds)
    pseudoMaximized = true
    sendToRenderer('window:state', getWindowStatePayload())
}

function restoreFromPseudoMaximize() {
    if(!mainWindow || mainWindow.isDestroyed()) {
        return
    }

    if(!pseudoMaximized) {
        return
    }

    const targetDisplay = getDisplayForWindow()
    const restored = getDefaultNormalBounds(targetDisplay)
    mainWindow.setBounds(restored)
    lastNormalBounds = restored

    pseudoMaximized = false
    sendToRenderer('window:state', getWindowStatePayload())
}

function restoreForDragFromMaximized(payload) {
    if(!mainWindow || mainWindow.isDestroyed()) {
        return { ok: false, maximized: false }
    }

    const wasMaximized = Boolean(mainWindow.isMaximized() || pseudoMaximized)
    if(!wasMaximized) {
        return { ok: true, maximized: false }
    }

    const cursorPoint = {
        x: Math.round(Number(payload?.screenX) || 0),
        y: Math.round(Number(payload?.screenY) || 0)
    }

    const display = getDisplayForWindow(cursorPoint)
    const workArea = display.workArea
    const targetBounds = getDefaultNormalBounds(display)
    const titlebarWidth = Math.max(1, Math.round(Number(payload?.titlebarWidth) || targetBounds.width))
    const offsetX = clamp(Number(payload?.offsetX) || Math.floor(titlebarWidth / 2), 0, titlebarWidth)
    const pointerRatio = clamp(offsetX / titlebarWidth, 0.1, 0.9)
    const targetX = clamp(
        Math.round(cursorPoint.x - (targetBounds.width * pointerRatio)),
        workArea.x,
        workArea.x + workArea.width - targetBounds.width
    )
    const titlebarHeight = Math.max(24, Math.round(Number(payload?.titlebarHeight) || 38))
    const targetY = clamp(
        Math.round(cursorPoint.y - Math.floor(titlebarHeight / 2)),
        workArea.y,
        workArea.y + workArea.height - targetBounds.height
    )

    if(mainWindow.isMaximized()) {
        mainWindow.unmaximize()
    }

    pseudoMaximized = false
    const nextBounds = {
        x: targetX,
        y: targetY,
        width: targetBounds.width,
        height: targetBounds.height
    }
    mainWindow.setBounds(nextBounds)
    lastNormalBounds = nextBounds

    pseudoMaximized = false
    sendToRenderer('window:state', getWindowStatePayload())
    return { ok: true, maximized: false }
}

async function closeActivePort() {
    if(!activePort) {
        return
    }

    const portToClose = activePort
    activePort = null

    await new Promise((resolve, reject) => {
        if(!portToClose.isOpen) {
            resolve()
            return
        }

        portToClose.close((error) => {
            if(error) {
                reject(error)
                return
            }
            resolve()
        })
    })
}

ipcMain.handle('serial:listPorts', async() => {
    const ports = await SerialPort.list()
    return ports.map((port) => ({
        path: port.path,
        manufacturer: port.manufacturer || '',
        serialNumber: port.serialNumber || '',
        vendorId: port.vendorId || '',
        productId: port.productId || ''
    }))
})

ipcMain.handle('serial:connect', async(_event, options) => {
    const portPath = options?.path
    const baudRate = Number(options?.baudRate) || 115200

    if(!portPath) {
        throw new Error('Port path is required')
    }

    await closeActivePort()

    const port = new SerialPort({
        path: portPath,
        baudRate,
        autoOpen: false
    })

    await new Promise((resolve, reject) => {
        port.open((error) => {
            if(error) {
                reject(error)
                return
            }
            resolve()
        })
    })

    activePort = port

    port.on('data', (chunk) => {
        sendToRenderer('serial:data', { text: chunk.toString('utf8') })
    })

    port.on('error', (error) => {
        sendToRenderer('serial:error', { message: error.message })
    })

    port.on('close', () => {
        sendToRenderer('serial:status', { connected: false, path: portPath })
    })

    sendToRenderer('serial:status', { connected: true, path: portPath, baudRate })
    return { ok: true }
})

ipcMain.handle('serial:disconnect', async() => {
    const wasConnectedPath = activePort?.path || ''
    await closeActivePort()
    sendToRenderer('serial:status', { connected: false, path: wasConnectedPath })
    return { ok: true }
})

ipcMain.handle('serial:write', async(_event, text) => {
    if(!activePort || !activePort.isOpen) {
        throw new Error('No open serial port')
    }

    const payload = typeof text === 'string' ? text : String(text)

    await new Promise((resolve, reject) => {
        activePort.write(payload, (error) => {
            if(error) {
                reject(error)
                return
            }
            resolve()
        })
    })

    return { ok: true, bytes: Buffer.byteLength(payload) }
})

ipcMain.handle('window:minimize', () => {
    if(mainWindow && !mainWindow.isDestroyed()) {
        mainWindow.minimize()
    }
    return { ok: true }
})

ipcMain.handle('window:toggleMaximize', () => {
    if(!mainWindow || mainWindow.isDestroyed()) {
        return { ok: false, maximized: false }
    }

    if(mainWindow.isMaximized()) {
        mainWindow.unmaximize()
        pseudoMaximized = false
        const display = getDisplayForWindow()
        const restored = getDefaultNormalBounds(display)
        mainWindow.setBounds(restored)
        lastNormalBounds = restored
        sendToRenderer('window:state', getWindowStatePayload())
    }
    else if(pseudoMaximized) {
        restoreFromPseudoMaximize()
    }
    else {
        applyPseudoMaximize()
    }

    return { ok: true, maximized: Boolean(mainWindow.isMaximized() || pseudoMaximized) }
})

ipcMain.handle('window:close', () => {
    if(mainWindow && !mainWindow.isDestroyed()) {
        mainWindow.close()
    }
    return { ok: true }
})

ipcMain.handle('window:getState', () => {
    return getWindowStatePayload()
})

ipcMain.on('window:prepareDragFromMaximizedSync', (event, payload) => {
    event.returnValue = restoreForDragFromMaximized(payload)
})

app.commandLine.appendSwitch('ignore-gpu-blocklist');
app.commandLine.appendSwitch('disable-gpu-sandbox');
app.commandLine.appendSwitch('enable-webgl2-compute-context');
app.commandLine.appendSwitch('disable-vulkan'); 

const createWindow = () => {
    const win = new BrowserWindow({
        width: 800,
        height: 600,
        frame: false,
        show: false,
        hasShadow: false,
        backgroundColor: '#050505',
        webPreferences: {
            preload: path.join(__dirname, 'preload.js'),
            nodeIntegration: false,
            contextIsolation: true,
        },
    })

    win.on('maximize', () => {
        pseudoMaximized = false
        sendToRenderer('window:state', getWindowStatePayload())
    })

    win.on('unmaximize', () => {
        trackLastNormalBounds()
        sendToRenderer('window:state', getWindowStatePayload())
    })

    win.on('move', () => {
        trackLastNormalBounds()
    })

    win.on('resize', () => {
        trackLastNormalBounds()
    })

    win.once('ready-to-show', () => {
        applyPseudoMaximize()
        win.show()
    })

    win.loadFile('index.html')
    mainWindow = win
}

app.whenReady().then(() => {
    createWindow()

    app.on('activate', () => {
        if (BrowserWindow.getAllWindows().length === 0) {
            createWindow()
        }
    })
})

app.on('window-all-closed', () => {
    if (process.platform !== 'darwin') {
        app.quit()
    }
})

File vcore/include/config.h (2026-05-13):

#pragma once
#include <HardwareSerial.h>
#include <TMC2209.h>

// Pin Definitions
#define TMC_EN 26
#define TURRET_ENDSTOP 23
#define SWEEPER_ENDSTOP 22
#define LUNA_TX 19
#define LUNA_RX 18
#define TMC_TX 16
#define TMC_RX 17

// Communication
#define ESP_CLOCK (12000000.0f / (1UL << 24))

#define LUNA_BAUD 115200
#define LUNA_HZ 250

#define TMC_BAUD 115200

#define HEARTBEAT_MS 1000
#if __has_include("secrets.h")
    #include "secrets.h"
#else
    #error "No secrets.h - Copy secrets.h.example to secrets.h and replace info."
#endif

// Motors
#define NEMA_STEPS_PER_REV 200

#define TURRET_PINION_TEETH 20
#define TURRET_PULLEY_TEETH 144
#define TURRET_GEAR_RATIO ((float)TURRET_PULLEY_TEETH / (float)TURRET_PINION_TEETH)
// #define TURRET_GEAR_RATIO 1
#define TURRET_USTEPS 2

#define SWEEPER_PINION_TEETH 25
#define SWEEPER_PULLEY_TEETH 45
#define SWEEPER_GEAR_RATIO ((float)SWEEPER_PULLEY_TEETH / (float)SWEEPER_PINION_TEETH)
// #define SWEEPER_GEAR_RATIO 1
#define SWEEPER_USTEPS 4

// Settings
#define AUTO_HOME false

#define TURRET_REVERSE false
#define SWEEPER_REVERSE false

#define TURRET_HOMING_RPS 0.5
#define SWEEPER_HOMING_RPS 0.5

#define SWEEPER_HEARTBEAT_HZ 50.0f

#define SWEEP_ANGLE 80.0F
#define SWEEP_MAX 80.0F
#define SWEEP_MIN -45.0F

// Test configuration (simple compile-time flags)
// Use #define constants for configuration. Do NOT use preprocessor conditionals
// (#if/#ifdef) for control flow in code; prefer runtime if statements for
// gating behavior. KISS.
#define TESTS_ENABLED true
#define TESTS_AUTO_RUN false
#define TESTS_ALLOW_ACTUATE true

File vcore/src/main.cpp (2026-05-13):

#include <Arduino.h>
#include "config.h"
#include "motion.h"
#include "relay.h"
#include "telemetry.h"
#include "kinematics.h"
#include "test.h"

String runtime_status = "idle";

uint32_t luna_us = 0;
uint32_t sweeper_us = 0;

uint32_t azimuth_us = 0;
float last_azimuth = 0.0f;
int i = 0;

void setup() {

    relay::setup_serial();
    relay::setup_relay();

    pinMode(TMC_EN, OUTPUT);
    pinMode(TURRET_ENDSTOP, INPUT_PULLDOWN);
    pinMode(SWEEPER_ENDSTOP, INPUT_PULLDOWN);

    digitalWrite(TMC_EN, LOW);

    relay::debug("Pins configured");

    delay(500);

    motion::setup_serial();
    telemetry::setup_serial();

    motion::setup_controllers();
    motion::enable_controllers();

    telemetry::setup_lidar();

    runtime_status = "idle";
    relay::send_status(runtime_status);

    if(AUTO_HOME) {
        runtime_status = "homing";
        relay::send_status(runtime_status);
        motion::home();
        runtime_status = "idle";
        relay::send_status(runtime_status);
    }

    if(TESTS_ENABLED) {
        if(TESTS_AUTO_RUN) {
            test::lidar_check();
            test::endstop_check();
        }
    }

    luna_us = micros();
    sweeper_us = micros();
}

void loop() {

    String instruction = relay::read_instruction();

    if(instruction == "") { return; }

    if(instruction == "status") {
        relay::send_status(runtime_status);
        return;
    }

    if(instruction == "stop") {
        motion::stop();
        runtime_status = "idle";
        relay::send_status(runtime_status);
        return;
    }

    if(instruction == "scan") {
        runtime_status = "homing";
        relay::send_status(runtime_status);
        motion::home();
        runtime_status = "idle";
        relay::send_status(runtime_status);

        runtime_status = "scanning";
        relay::send_status(runtime_status);
        motion::heartbeat();
        motion::start_scan();

        motion::heartbeat();

        uint32_t luna_us = micros();
        uint32_t sweeper_us = micros();

        while(true) {
            if(relay::read_instruction() == "stop") {
                motion::stop();
                runtime_status = "idle";
                relay::send_status(runtime_status);
                break;
            }

            motion::heartbeat();

            if(micros() - luna_us >= 1000000.0f / (float)LUNA_HZ) {
                relay::send(telemetry::get_distance(), motion::get_azimuth(), motion::get_elevation());
                luna_us = micros();
            }

            if(micros() - sweeper_us >= 1000000.0f / (float)SWEEPER_HEARTBEAT_HZ) {
                motion::sweeper_heartbeat();
                sweeper_us = micros();
            }

            if(motion::scan_finished()) {
                motion::stop();
                motion::home();
                relay::debug("Scan finished");
                runtime_status = "idle";
                relay::send_status(runtime_status);
                break;
            }
        }

        return;
    }

    if(instruction == "home") {
        runtime_status = "homing";
        relay::send_status(runtime_status);
        motion::home();
        runtime_status = "idle";
        relay::send_status(runtime_status);
        return;
    }

    if(TESTS_ENABLED) {
        if(instruction == "lidar") {
            test::lidar_check();
            relay::send_status(runtime_status);
            return;
        }
        if(instruction == "lidar_two_way") {
            test::lidar_two_way_check();
            relay::send_status(runtime_status);
            return;
        }
        if(instruction == "lidar_restore_manual") {
            test::lidar_restore_manual();
            relay::send_status(runtime_status);
            return;
        }

        if(instruction == "endstops") {
            test::endstop_check();
            relay::send_status(runtime_status);
            return;
        }

        if(instruction == "lidar_stream") {
            test::lidar_stream();
            relay::send_status(runtime_status);
            return;
        }

        if(instruction == "endstop_stream") {
            test::endstop_stream();
            relay::send_status(runtime_status);
            return;
        }

        if(instruction == "motor_run") {
            if(TESTS_ALLOW_ACTUATE) {
                test::motor_run_check();
            }
            else {
                relay::debug("motor_run disabled in config.h");
            }
            relay::send_status(runtime_status);
            return;
        }

        if(instruction == "motor_move") {
            if(TESTS_ALLOW_ACTUATE) {
                test::motor_move_check();
            }
            else {
                relay::debug("motor_move disabled in config.h");
            }
            relay::send_status(runtime_status);
            return;
        }

        if(instruction == "sweeper_test") {
            runtime_status = "testing";
            relay::send_status(runtime_status);
            test::sweeper_test();
            runtime_status = "idle";
            relay::send_status(runtime_status);
            return;
        }

        if(instruction == "sweeper_test_90") {
            runtime_status = "testing";
            relay::send_status(runtime_status);
            test::sweeper_test_constant_speed();
            runtime_status = "idle";
            relay::send_status(runtime_status);
            return;
        }

        if(instruction == "turret_vel") {
            runtime_status = "testing";
            relay::send_status(runtime_status);
            motion::run_turret_velocity((int)kinematics::turret_usteps_per_period(TURRET_VELOCITY_RPS));
            runtime_status = "idle";
            relay::send_status(runtime_status);
            return;
        }
    }
}

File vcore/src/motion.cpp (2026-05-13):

#include "config.h"
#include "kinematics.h"
#include "telemetry.h"
#include "relay.h"

namespace motion {

    HardwareSerial & serial_motor = Serial2;

    TMC2209 turret_motor;
    TMC2209 sweeper_motor;

    float current_turret_usteps = 0.0f;
    float start_turret_us = 0;
    float current_sweeper_usteps = 0.0f;
    float current_turret_velocity_usteps_per_second = 0.0f;
    float current_sweeper_velocity_usteps_per_second = 0.0f;

    uint32_t last_heartbeat_us = 0;

    float get_azimuth() {
        return fmod((current_turret_usteps / kinematics::turret_usteps_to_degrees()) + 360.0f, 360.0f);
    }

    float get_elevation() {
        return current_sweeper_usteps / kinematics::sweeper_usteps_to_degrees();
    }

    void set_elevation(float elevation) {
        current_sweeper_usteps = elevation * kinematics::sweeper_usteps_to_degrees();
    }

    void setup_serial() {
        relay::debug("Motor serial configured");
    }

    void setup_controllers() {
        turret_motor.setup(serial_motor, TMC_BAUD, TMC2209::SERIAL_ADDRESS_0, TMC_RX, TMC_TX);
        sweeper_motor.setup(serial_motor, TMC_BAUD, TMC2209::SERIAL_ADDRESS_1, TMC_RX, TMC_TX);
        relay::debug("Motor UART configured");

        turret_motor.setHardwareEnablePin(TMC_EN);
        sweeper_motor.setHardwareEnablePin(TMC_EN);
        relay::debug("Motor EN pin configured");

        turret_motor.setMicrostepsPerStepPowerOfTwo(TURRET_USTEPS);
        sweeper_motor.setMicrostepsPerStepPowerOfTwo(SWEEPER_USTEPS);
        relay::debug("Motor microsteps configured");

        turret_motor.setStandstillMode(TMC2209::FREEWHEELING);
        sweeper_motor.setStandstillMode(TMC2209::STRONG_BRAKING);
        relay::debug("Motor brake mode configured");

        turret_motor.setRunCurrent(40);
        sweeper_motor.setRunCurrent(70);

        turret_motor.enableStealthChop();
        // turret_motor.disableStealthChop();
        sweeper_motor.disableStealthChop(); // breaks the controller for some reason
        // sweeper_motor.enableStealthChop();

    }

    void enable_controllers() {
        turret_motor.enable();
        sweeper_motor.enable();
        relay::debug("Motors enabled");
    }

    void disable_controllers() {
        turret_motor.disable();
        sweeper_motor.disable();
        relay::debug("Motors disabled");
    }

    void run_turret_velocity(float velocity) {
        turret_motor.moveAtVelocity((int32_t)velocity);
        current_turret_velocity_usteps_per_second = kinematics::usteps_per_period_to_usteps_per_second(velocity);
        current_turret_usteps = 0;
        start_turret_us = micros();
        // relay::debug("Set turret velocity: " + String((int)velocity));
    }

    void run_sweeper_velocity(float velocity) {
        sweeper_motor.moveAtVelocity((int32_t)velocity);
        current_sweeper_velocity_usteps_per_second = -kinematics::usteps_per_period_to_usteps_per_second(velocity);
        // relay::debug("Set sweeper velocity: " + String((int)velocity));
    }

    void home_turret() {
        turret_motor.setStandstillMode(TMC2209::STRONG_BRAKING);

        motion::run_turret_velocity((int)kinematics::turret_homing_usteps_per_period());
        while(telemetry::turret_endstop_triggered()) {}
        motion::run_turret_velocity(0);
        relay::debug("Turret out of endstop");

        motion::run_turret_velocity((int)kinematics::turret_homing_usteps_per_period());
        while(!telemetry::turret_endstop_triggered()) {}
        motion::run_turret_velocity(0);
        relay::debug("Turret at endstop");


        current_turret_usteps = 0;
        turret_motor.setStandstillMode(TMC2209::FREEWHEELING);
        relay::debug("Turret homed");
    }

    void home_sweeper() {
        sweeper_motor.setStandstillMode(TMC2209::STRONG_BRAKING);

        int32_t down_target_usteps = 90.0f * kinematics::sweeper_usteps_to_degrees();
        int32_t up_target_usteps = 180.0f * kinematics::sweeper_usteps_to_degrees();
        uint32_t down_duration_ms = (down_target_usteps * 1000.0f) / kinematics::sweeper_homing_usteps_per_second();
        uint32_t up_duration_limit_ms = (up_target_usteps * 1000.0f) / kinematics::sweeper_homing_usteps_per_second();

        motion::run_sweeper_velocity(-(int)kinematics::sweeper_homing_usteps_per_period());
        delay(down_duration_ms);
        motion::run_sweeper_velocity(0);

        relay::debug("Sweeper moved down");

        uint32_t up_start_ms = millis();
        motion::run_sweeper_velocity((int)kinematics::sweeper_homing_usteps_per_period());
        while(!telemetry::sweeper_endstop_triggered() && (millis() - up_start_ms < up_duration_limit_ms)) {}
        motion::run_sweeper_velocity(0);
        relay::debug("Sweeper moved up");

        current_sweeper_usteps = 0;
        sweeper_motor.setStandstillMode(TMC2209::STRONG_BRAKING);
        relay::debug("Sweeper homed");
    }

    void heartbeat() {
        uint32_t dt_us = micros() - last_heartbeat_us;

        // current_turret_usteps += (current_turret_velocity_usteps_per_second * dt_us) / 1000000.0f;

        current_turret_usteps = current_turret_velocity_usteps_per_second * ((float)(micros() - start_turret_us) / 1000000.0f);

        if(telemetry::turret_endstop_triggered()) {
            current_turret_usteps = 0;
            start_turret_us = micros();
            // relay::debug("Turret endstop hit, resetting turret position");
        }

        current_sweeper_usteps += (current_sweeper_velocity_usteps_per_second * dt_us) / 1000000.0f;

        last_heartbeat_us = micros();
    }

    void sweeper_heartbeat() {
        float w_sweeper = W_BASE / cos(get_elevation() * (PI / 180.0f));
        float usteps_per_period = kinematics::rps_to_usteps_per_period(w_sweeper, NEMA_STEPS_PER_REV, SWEEPER_GEAR_RATIO, SWEEPER_USTEPS, ESP_CLOCK);
        motion::run_sweeper_velocity(-usteps_per_period);

        // relay::debug("Sweeper heartbeat:" + String(usteps_per_period) + " usteps/s" + " w_sweeper: " + String(w_sweeper) + " get_elevation: " + String(get_elevation()));
    }

    void home() {
        home_turret();
        home_sweeper();
        relay::debug("Homing complete");
    }

    void start_scan() {
        int32_t down_target_usteps = -SWEEP_MIN * kinematics::sweeper_usteps_to_degrees(); // Need negative because of motor fuckery.
        uint32_t down_duration_ms = (down_target_usteps * 1000.0f) / kinematics::sweeper_homing_usteps_per_second();

        motion::run_sweeper_velocity((int)kinematics::sweeper_homing_usteps_per_period());
        delay(down_duration_ms);
        motion::run_sweeper_velocity(0);

        motion::set_elevation(SWEEP_MIN);


        motion::run_turret_velocity((int)kinematics::turret_usteps_per_period(TURRET_VELOCITY_RPS));
    }

    bool scan_finished() {
        return motion::get_elevation() >= SWEEP_MAX;
    }

    void stop() {
        motion::run_turret_velocity(0);
        motion::run_sweeper_velocity(0);
    }
}

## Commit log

2026-03-17 WIP BOM
2026-03-17 Nearly complete BOM
2026-03-20 Update BOM, Create TODO list, Start PCB
    [vdar.kicad_pcb, vdar.kicad_sch]
2026-03-24 Update Everything
    [bill_of_materials.csv, vdar.kicad_pcb, vdar.kicad_sch]
2026-03-24 Add offboard wiring schematic
    [offboard.kicad_sch, vdar.kicad_sch]
2026-03-24 Complete Bill of Materials
    [bill_of_materials.csv]
2026-03-24 Swap bolt vendors
    [bill_of_materials.csv, purchase_order.csv]
2026-03-24 Change CSV Separator
    [bill_of_materials.csv, purchase_order.csv]
2026-03-24 Fix formatting in purchase_order.csv
    [purchase_order.csv]
2026-03-24 Update BOM & Fastenal PO
    [bill_of_materials.csv]
2026-03-25 Minor BoM vendor update (ali -> lee's)
    [bill_of_materials.csv, purchase_order.csv]
2026-03-25 Optimize timing belt
    [bill_of_materials.csv, purchase_order.csv]
2026-03-26 Update BoM/PO
    [bill_of_materials.csv, purchase_order.csv]
2026-03-26 Add gerbers & update readmes
    [bill_of_materials.csv, purchase_order.csv]
2026-03-26 Add vdar_pcb.zip
    [purchase_order.csv]
2026-03-29 Add silkscreen to PCB
    [vdar.kicad_pcb]
2026-04-03 Move finances & Add assembly
    [bill_of_materials.csv, purchase_order.csv]
2026-04-07 Update on-hand materials
    [bill_of_materials.csv, purchase_order.csv]
2026-04-09 Add WIRENETS.md
2026-04-19 Update parts on-hand & recreate todo.md
    [bill_of_materials.csv]
2026-04-30 Working motors, endstops, & lidar readings
    [bill_of_materials.csv]
